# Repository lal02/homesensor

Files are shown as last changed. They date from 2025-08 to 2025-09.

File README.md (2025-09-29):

# homesensor

## Description
This project, which is built around the esp32 microcontroller, started out as a simple [Spring Application](https://github.com/lal02/Centralized-Web-Application) while I was doing an internship as a part of my university's practical semester. 
The goal of the Spring Application was to get familiar with Spring in general.

The Spring application mentioned above has additional features that are not relevant to the homesensor setup and will therefore not be discussed in this repository.

The idea was to use the esp32 as a data source to get some hands-on experience with REST interfaces and Data Handling in Spring. 
Beyond just being a learning exercise, this project turned out to be really useful. 
By collecting and graphing temperature data, I was able to spot a problem with the underfloor heating in my apartment.

The esp32 collects data from a variety of sensors and transmits it to the Spring backend through REST interfaces. 
The Spring backend, in turn, offers multiple REST interfaces for both sending and retrieving data. 
Additionally, a Raspberry Pi controls a 64x64 LED matrix, which displays data received from the Spring backend. 
It also adjusts the brightness of the LED matrix based on the light intensity data obtained.

## Overview
This sketch illustrates the structure of all the hardware and software components, as well as how they interact with each other.

<br> </br>
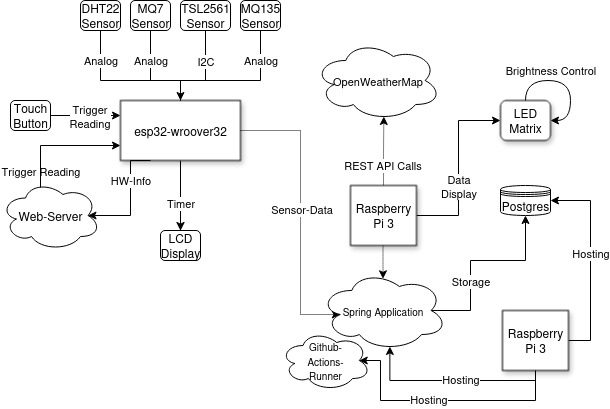
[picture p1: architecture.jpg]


## Esp32 and Sensor Integration
The project commenced as a modest undertaking, utilising an ESP32 microcontroller and a DHT22 sensor to gather and transmit temperature and humidity data. 
Subsequent to this, the setup was expanded by the addition of further sensors, including the TSL2561 for the purpose of measuring light intensity, and subsequently the MQ7 and MQ135 for the purpose of measuring air quality. 
In order to enhance the ease of use, a number of quality-of-life features have been incorporated. 
These included an LCD screen that displayed the IP address and the time until the next sensor reading. 
Furthermore, an HTTP server was configured on the ESP32, incorporating two endpoints. 
The primary endpoint facilitates the retrieval of hardware-related information in the form of an HTML file, encompassing details such as the IP address, MAC address, host name, WiFi SSID, and the list of connected sensors along with their respective functions. 
In conclusion, a touch button was incorporated, the actuation of which initiates a sensor reading.
Presently, both the ESP32 and the sensors are stored within a cardboard box. 
This short term storage method will be replaced in the future by a custom 3D printed case.

## Raspberry Pi no.1 
The system is constructed around a Raspberry Pi 3, which hosts a variety of essential services. 
The system operates a Tomcat service, which contains a Spring application, thereby providing a robust backend for the management of a variety of tasks. 
Furthermore, the Raspberry Pi is equipped with a GitHub Actions runner, thereby enabling DevOps processes and continuous integration/continuous deployment (CI/CD) pipelines. 
It also manages a PostgreSQL database, thereby enabling efficient data storage and management.
It is evident that when a multitude of applications are operating concurrently, the Raspberry Pi 3 reaches its maximum performance capacity. 
During periods of substantial data loading, such as retrieving large amounts of data via a REST Interface Call, the system encounters performance bottlenecks. 
This performance limitation suggests that, in the future, it might be beneficial to transfer these operations to a machine with greater computing power to ensure smoother and more efficient processing.

## Raspberry Pi no.2
The Raspberry Pi is programmed to execute a Python script that enables the control of a connected 64x64 LED matrix. 
However, it should be noted that due to the utilisation of Python bindings, the performance is less than optimal which causes visible flickers caused by low Hz. 
The present script has been developed for interaction with the REST interface of a Spring application, with a view to both the display of data and the regulation of the brightness of the LED matrix. 
This objective is realised through the retrieval of the most recent light intensity data, which is then utilised to adjust the brightness. 
Furthermore, the script utilises the API of OpenWeatherMap to retrieve current weather information, thereby integrating external data into the display system.

<br> </br>

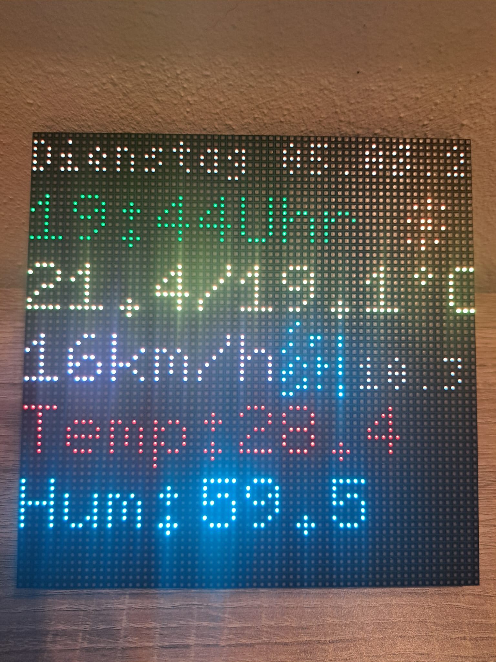
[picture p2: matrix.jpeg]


## PCB
With the help of a friend I managed to design a pcb using KiCad and ordered it from pcbway.
The PCB-Design is very basic and still has room for improvement. 
This is an area where I had no previous experience in and I learned a lot from tinkering around with KiCad.


## Learnings
Throughout this project, I've gained a variety of skills and knowledge. 
This includes for example soldering and electronics, which were essential for building and troubleshooting hardware. 
I learned about the I2C protocol for device communication and improved my ability to read datasheets for component specifications. 
My Linux skills advanced, particularly in system configuration and hardware interaction. 
Additionally, I developed an understanding of hardware requirements, such as program storage size and computational power for running httpservers.

# Potential Upgrades
In the future, there are a number of potential enhancements that could be made to this project. 
A notable enhancement would be Over-the-Air (OTA) updates on the esp32. 
This feature facilitates seamless, wireless updates to the system, thereby ensuring that upgrades and maintenance can be effortlessly executed without the necessity for physical access to the device.
Furthermore, the utilisation of the available C++ bindings for the LED matrix is another possibility..
This would enhance performance and efficiency by leveraging the capabilities of C++, which has been demonstrated to offer superior resource management and faster execution compared to Python.

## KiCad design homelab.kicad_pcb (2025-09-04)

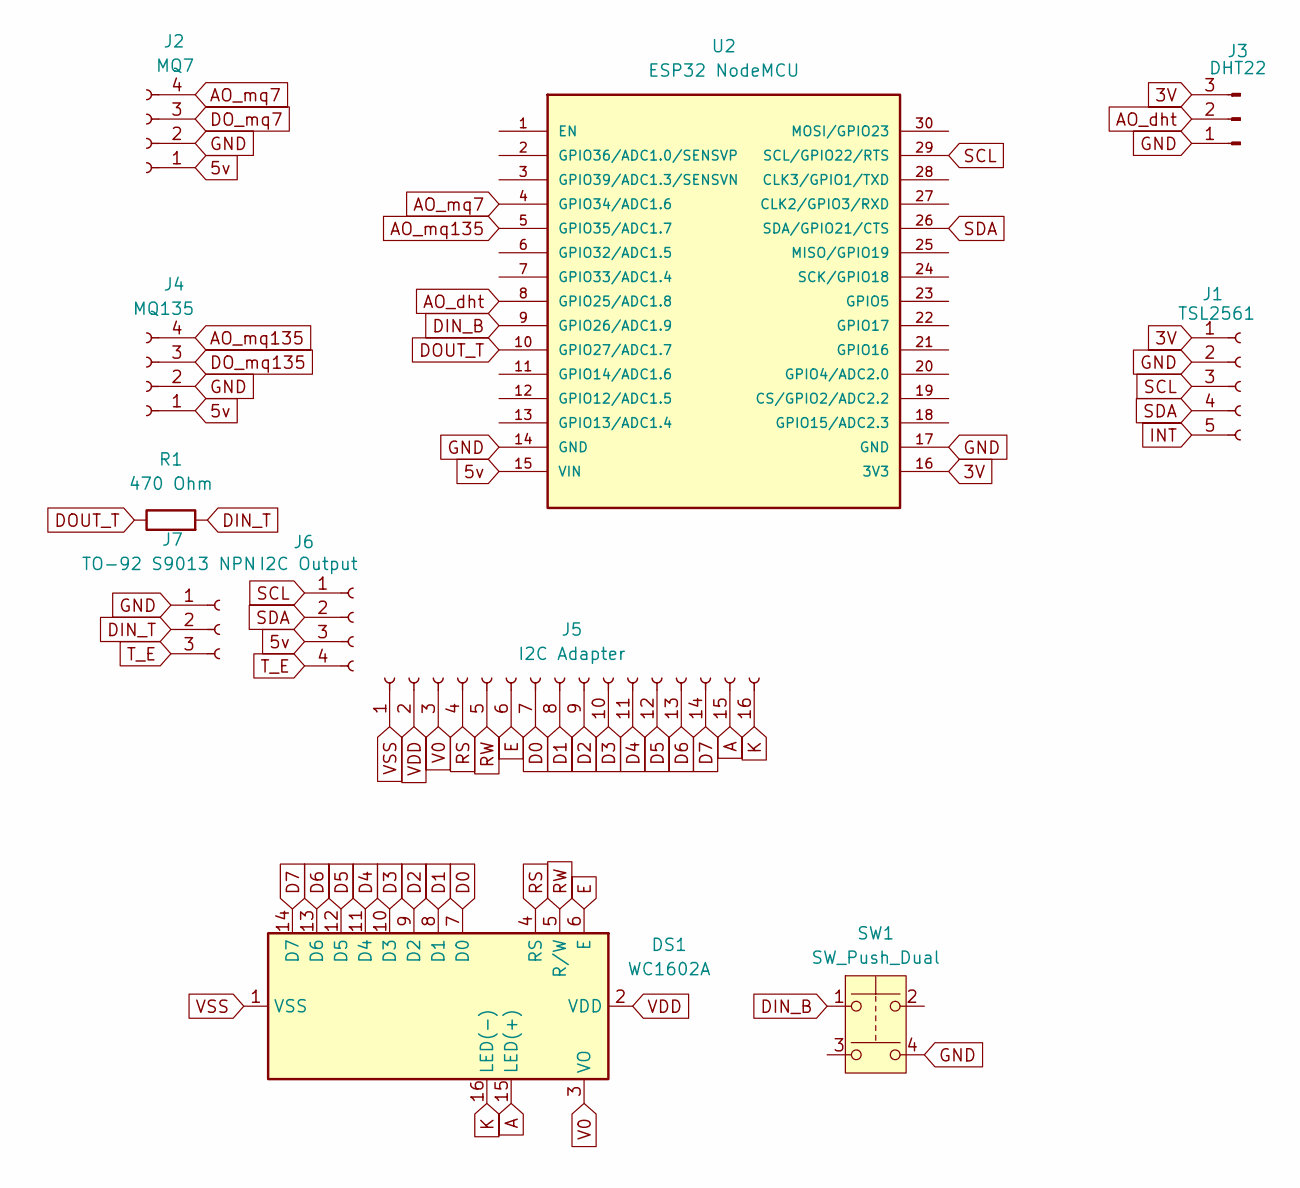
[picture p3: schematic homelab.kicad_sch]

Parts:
DS1: WC1602A
J1: TSL2561; PinSocket_1x05_P2.54mm_Vertical
J2: MQ7; PinSocket_1x04_P2.54mm_Horizontal
J3: DHT22; PinHeader_1x03_P2.54mm_Vertical
J4: MQ135; PinSocket_1x04_P2.54mm_Horizontal
J5: I2C Adapter; PinSocket_1x16_P2.54mm_Vertical
J6: I2C Output; PinHeader_1x04_P2.54mm_Vertical
J7: TO-92 S9013 NPN; PinSocket_1x03_P2.54mm_Vertical
R1: 470 Ohm; R_Axial_DIN0204_L3.6mm_D1.6mm_P1.90mm_Vertical
SW1: SW_Push_Dual; SW_PUSH_6mm
U2: ESP32 NodeMCU; ESP32-C3-DevKitM-1; PARTREV 23/04/2025

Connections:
3V: J1.1, J3.3, U2.16 (3V3)
5v: J2.1, J4.1, J6.3, U2.15 (VIN)
A: DS1.15 (LED(+)), J5.15
AO_dht: J3.2, U2.8 (GPIO25/ADC1.8)
AO_mq7: J2.4, U2.4 (GPIO34/ADC1.6)
AO_mq135: J4.4, U2.5 (GPIO35/ADC1.7)
D0: DS1.7 (D0), J5.7
D1: DS1.8 (D1), J5.8
D2: DS1.9 (D2), J5.9
D3: DS1.10 (D3), J5.10
D4: DS1.11 (D4), J5.11
D5: DS1.12 (D5), J5.12
D6: DS1.13 (D6), J5.13
D7: DS1.14 (D7), J5.14
DIN_B: SW1.1, U2.9 (GPIO26/ADC1.9)
DIN_T: J7.2, R1.2
DOUT_T: R1.1, U2.10 (GPIO27/ADC1.7)
DO_mq7: J2.3
DO_mq135: J4.3
E: DS1.6 (E), J5.6
GND: J1.2, J2.2, J3.1, J4.2, J7.1, SW1.4, U2.14 (GND), U2.17 (GND)
INT: J1.5
K: DS1.16 (LED(-)), J5.16
RS: DS1.4 (RS), J5.4
RW: DS1.5 (R/W), J5.5
SCL: J1.3, J6.1, U2.29 (SCL/GPIO22/RTS)
SDA: J1.4, J6.2, U2.26 (SDA/GPIO21/CTS)
T_E: J6.4, J7.3
V0: DS1.3 (VO), J5.3
VDD: DS1.2 (VDD), J5.2
VSS: DS1.1 (VSS), J5.1

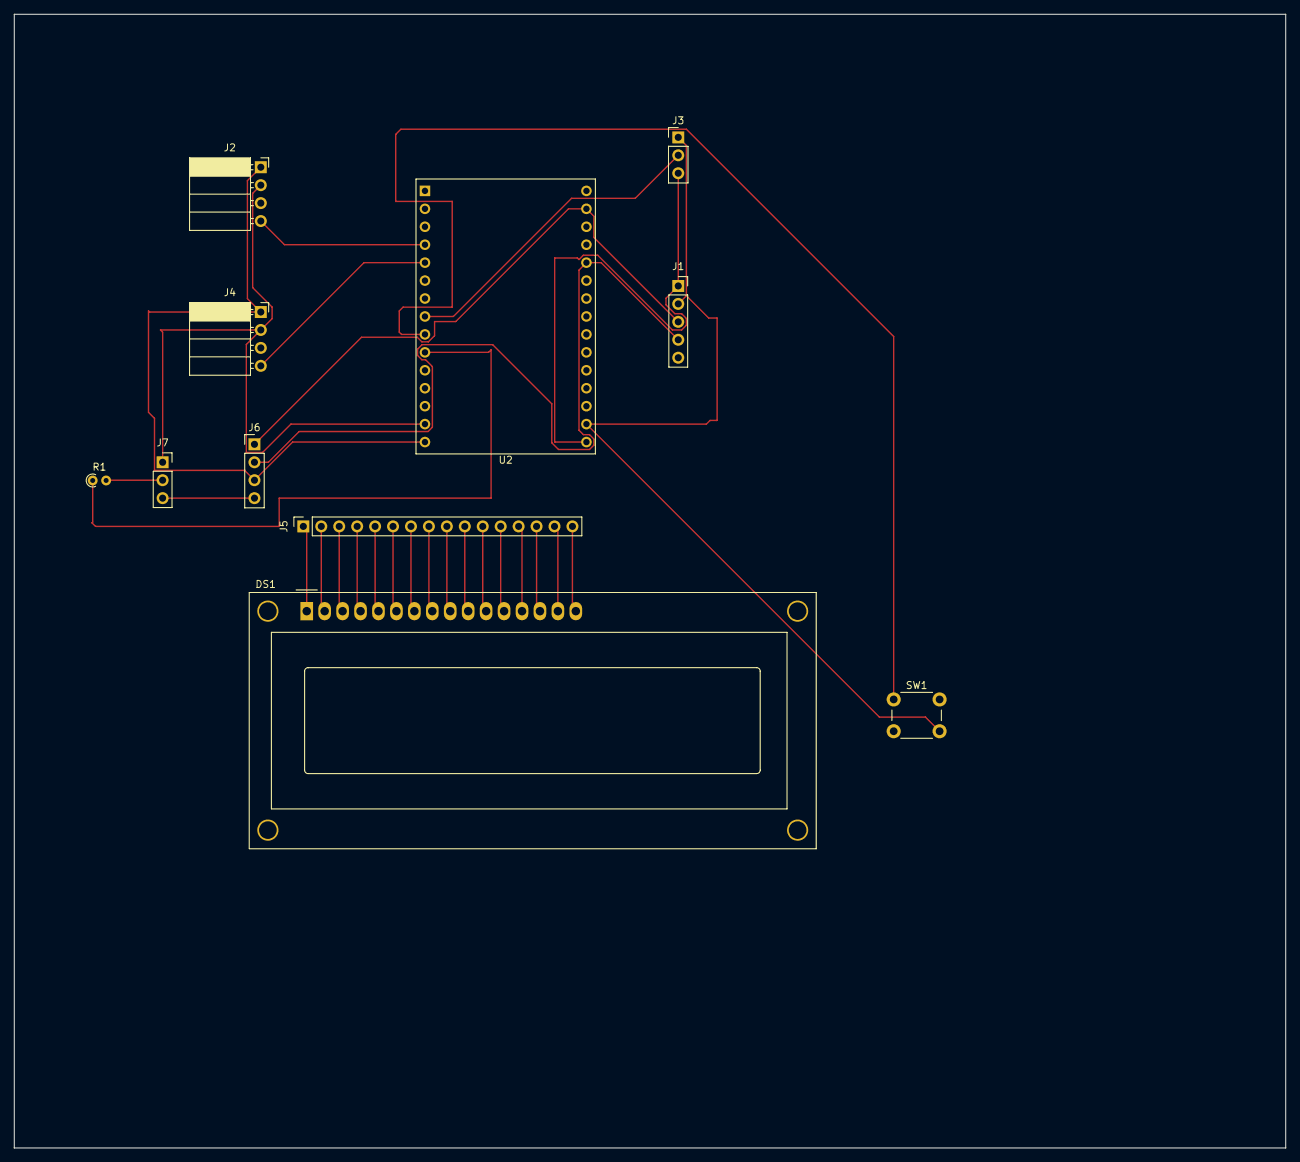
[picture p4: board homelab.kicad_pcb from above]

Board: 2 copper layers, 180.0 x 160.5 mm, 11 parts (0 on the bottom side), 28 nets.

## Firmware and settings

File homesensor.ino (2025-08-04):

#include <Adafruit_Sensor.h>
#include "Adafruit_TSL2561_U.h"

#include <DHT.h>
#include <DHT_U.h>

#include <WiFi.h>
#include <WebServer.h>
#include <HTTPClient.h>

#include <time.h>

#include <Wire.h>
#include <LiquidCrystal_I2C.h>


const int MQ135Pin = 35;
const int MQ7Pin = 34; 
const char WIFI_SSID[] = "IoT-WiFi";         
const char WIFI_PASSWORD[] = "HEhVy77356"; 
const String HOST_NAME   = "http://10.0.10.56:8080"; 
const char* ntpServer = "pool.ntp.org";
const long utcOffsetInSeconds = 7200; // UTC +2
const int interval = 900000; // 15 minutes
unsigned long previousMillis = 0;
unsigned long currentMillis;
const int buttonPin = 26;
int lastButtonState = HIGH;
#define DHTPIN 25     
#define DHTTYPE DHT22     
DHT_Unified dht(DHTPIN, DHTTYPE);
Adafruit_TSL2561_Unified tsl = Adafruit_TSL2561_Unified(TSL2561_ADDR_FLOAT);
WebServer server(80);
LiquidCrystal_I2C lcd(0x27, 16, 2);

void setup() {
  Serial.begin(115200);
  WiFi.begin(WIFI_SSID,WIFI_PASSWORD);
  while (WiFi.status() != WL_CONNECTED) {
    WiFi.begin(WIFI_SSID,WIFI_PASSWORD);
    Serial.println("WiFi not connected!");
    delay(1000);
    int n = WiFi.scanNetworks();
    for (int i = 0; i < n; i++) {
      Serial.println(WiFi.SSID(i));
    }
  }
  const String ipaddr = WiFi.localIP().toString().c_str();
  Serial.println("WiFi setup finished");
  
  //setup dht22 sensor
  Serial.println("dht22 setup");
  sensor_t sensor;
  dht.begin();
  dht.temperature().getSensor(&sensor);
  dht.humidity().getSensor(&sensor);
  Serial.println("dht22 setup finished");
  // NTP-Server synchronisieren
  configTime(utcOffsetInSeconds, 0, ntpServer);
  Serial.println("time config finished");
  
  // setup light sensor tsl251
  tsl.setGain(TSL2561_GAIN_1X);
  tsl.setIntegrationTime(TSL2561_INTEGRATIONTIME_402MS);
  Serial.println("TSL2561 setup finished");

  pinMode(MQ7Pin,INPUT);
  Serial.println("mq7 setup finished");
  pinMode(MQ135Pin,INPUT);
  Serial.println("mq135 setup finished");
  pinMode(buttonPin,INPUT);
  Serial.println("touch button setup finished");
  
  server.on("/read", serverTriggerRead);
  server.on("/",hardwareInfoOutput);
  server.begin();
  Serial.println("server setup finished");

  lcd.init();
  lcd.backlight();
  lcd.setCursor(0, 0);
  const String firstrow = "IP:" + ipaddr + ":80";
  lcd.print(firstrow);  
  lcd.setCursor(0, 1);
  lcd.print("Next in:");
  Serial.println("lcd setup finished");
    
}

void loop() {
  server.handleClient();
  // 15 minute interval reading
  currentMillis = millis();
  if (currentMillis - previousMillis >= interval) {
    serverTriggerRead();
    previousMillis = currentMillis;
  }
  // remainingTime in seconds
  unsigned int remainingTime = (interval/1000) - (currentMillis-previousMillis)/1000;
  printRemainingTime(remainingTime);
 
  // button press triggered reading
  int buttonState = digitalRead(buttonPin);
  if (buttonState == LOW && lastButtonState == HIGH) {
    Serial.println("Button pressed");
    serverTriggerRead();
  }
  lastButtonState = buttonState;
  delay(50);
}

void serverTriggerRead(){
  Serial.println("http server triggered, reading and processing data");
  readAndSendData();
  previousMillis=currentMillis;
  server.send(200, "text/plain", "OK");
}

void readAndSendData(){
  if ((WiFi.status() != WL_CONNECTED)) {
  Serial.print(millis());
  Serial.println("Reconnecting to WiFi...");
  WiFi.disconnect();
  WiFi.reconnect();
  }
  //get current timestamp from server
  struct tm timeinfo;
  getLocalTime(&timeinfo);
  char buffer[20]; 
  strftime(buffer, sizeof(buffer), "%Y-%m-%dT%H:%M:%S", &timeinfo);
  Serial.println("current timestamp : " + String(buffer));
  //read temperature data from dht22 sensor
  sensors_event_t event;
  dht.temperature().getEvent(&event);
  if (isnan(event.temperature)) {
    Serial.println(F("Error reading temperature!"));
  }
  else {
    sendHttpRequest("/temperature", String(event.temperature), String(buffer));
  }
  // read humidity data from dht22 sensor
  dht.humidity().getEvent(&event);
  if (isnan(event.relative_humidity)) {
    Serial.println(F("Error reading humidity!"));
  }
  else {
    Serial.print(event.relative_humidity);
    sendHttpRequest("/humidity", String(event.relative_humidity), String(buffer));
  }
  // read light data from TSL2561 sensor
  sensors_event_t lightEvent;
  tsl.getEvent(&lightEvent);
  if (event.light) {
   sendHttpRequest("/light", String(lightEvent.light), String(buffer));
  } else {
    Serial.print("Sensor overload sending 0 Lux instead");
    sendHttpRequest("/light", "0.0", String(buffer));
 }
  // Air quality sensor MQ135
  sendHttpRequest("/airquality",String(analogRead(MQ135Pin)),String(buffer));
  // CO sensor MQ7
  sendHttpRequest("/co",String(analogRead(MQ7Pin)),String(buffer));
}


void sendHttpRequest(String URL, String value,String timestamp){
  HTTPClient http;
  http.begin(HOST_NAME + URL);
  http.addHeader("Content-Type", "application/json");
  String payload = "{";
  payload += "\"value\":\"" + value + "\",";
  payload += "\"timestamp\":\"" + timestamp + "\"";
  payload += "}";
  int httpCode = http.POST(payload);
  http.end();
  Serial.print("HTTP Return Code of request to : ");
  Serial.print (" " + URL);
  Serial.print(" with value: " + value + " and timestamp " + timestamp);
  Serial.println(httpCode);
}

String formatNumber(int number, int width) {
  String result = String(number);
  while (result.length() < width) {
    result = "0" + result;
  }
  return result;
}

void printRemainingTime(int seconds){
  lcd.setCursor(9, 1);
  lcd.print(formatNumber(seconds/60,2));
  lcd.setCursor(11,1);
  lcd.print("m ");
  lcd.setCursor(12,1);
  lcd.print(formatNumber(seconds%60,2));
  lcd.setCursor(14,1);
  lcd.print("s");
}

void hardwareInfoOutput(){
    String html = "<!DOCTYPE HTML>";
    html += "<html>";
    html += "<head>";
    html += "<link rel=\"icon\" href=\"data:,\">";
    html += "</head>";
    html += "<h4> Hardware Info </h4> ";
    html += "Host-Name: " + String(WiFi.getHostname())+ " <br>";
    html += "Connected WiFi-SSID: " + String(WiFi.SSID()) + "<br>";
    html += "IP-Adress: " + String(WiFi.localIP().toString().c_str()) + " <br>";
    html += "MAC-Adress: " + String(WiFi.macAddress()) + " <br";
    html += "</p>";
    html += "<h4> Sensor Info </h4> ";
    html += "DHT22: Temperature and Humidity Sensor <br>";
    html += "TSL2561: Luminosity / Lux Calculation Sensor <br>";
    html += "MQ7: Carbon Monoxide Sensor <br>";
    html += "MQ35: Gas Sensor for Air Quality <br>";
    html += "</html>";
    server.send(200, "text/html", html);
}

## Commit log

2025-08-04 updated version to current state
2025-08-17 PCB Backup
    [esp32_test.kicad_pcb, esp32_test.kicad_sch]
2025-09-04 remove obsolete files
    [esp32_test.kicad_pcb, esp32_test.kicad_sch]
2025-09-29 Update README.md, added pcb description
